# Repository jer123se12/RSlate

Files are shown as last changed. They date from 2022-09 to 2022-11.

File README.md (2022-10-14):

# RSlate
A 40key acrylic stack keyboard that is either hotswap with low profile switches or normal one but not hotswap.
Supports Vial
Currently Done!
---
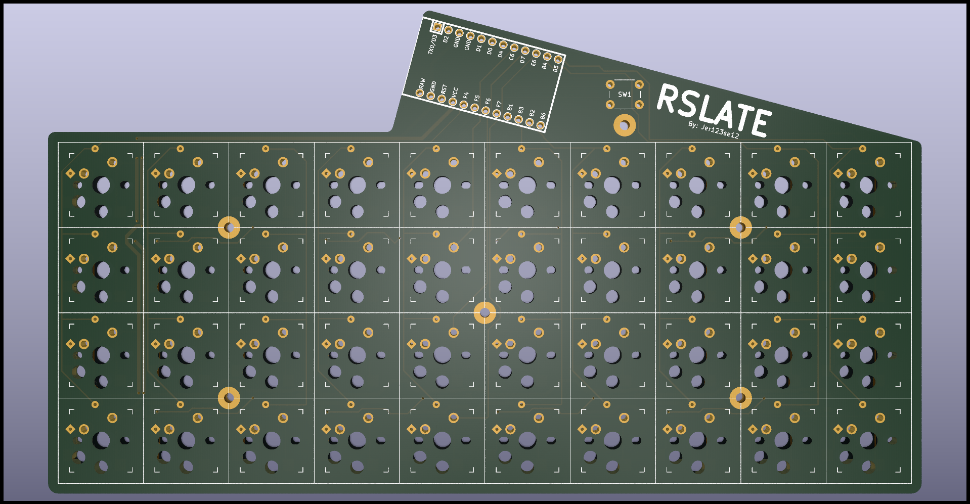
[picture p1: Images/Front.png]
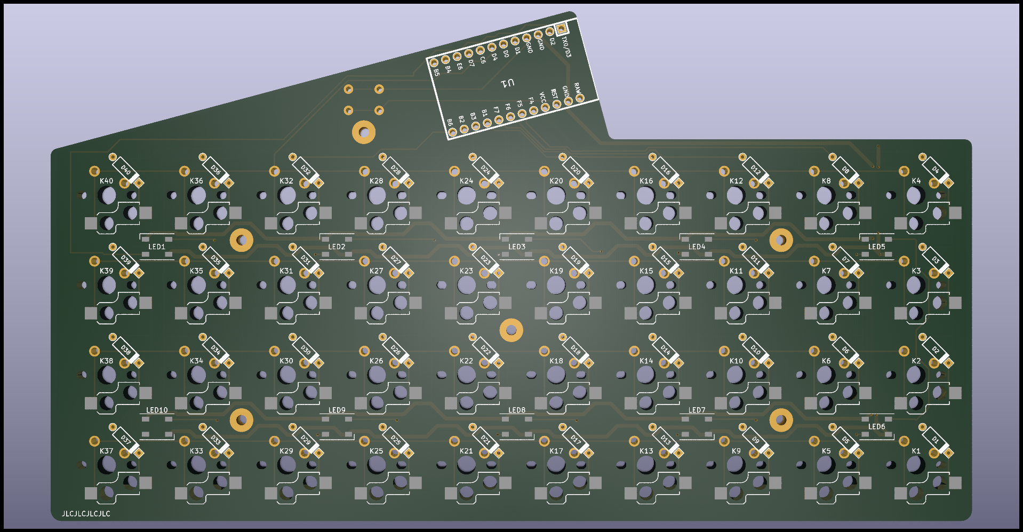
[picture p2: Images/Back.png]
|||
|---|---|
|Front|Back|
---
3d files are at [here](https://cad.onshape.com/documents/8e13d1f4745863165f092818/w/d03652fcd09787199e2b8651/e/c43cd68ad85962de6582dd97)

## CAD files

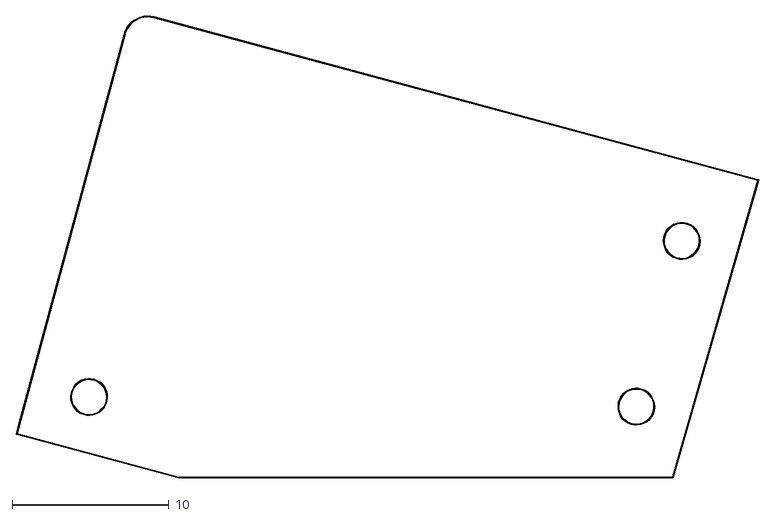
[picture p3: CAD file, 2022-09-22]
kicad/Final Files/plate/promicro.dxf
47.3 x 29.4

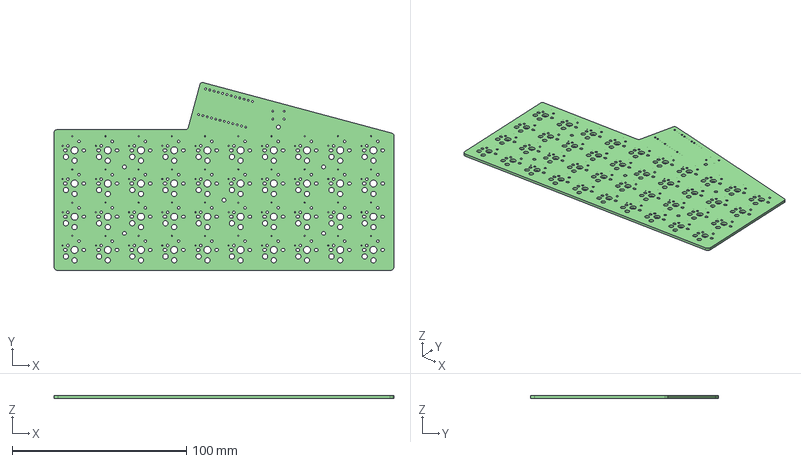
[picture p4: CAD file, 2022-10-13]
kicad/V4.step
195.1 x 107.9 x 1.60 mm

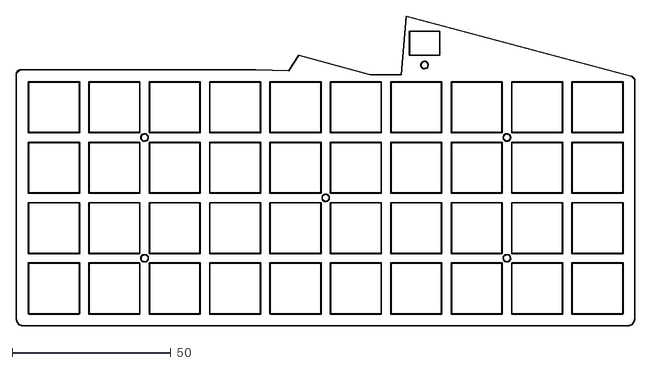
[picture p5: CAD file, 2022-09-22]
kicad/Final Files/plate/middle.dxf
195.1 x 97.8

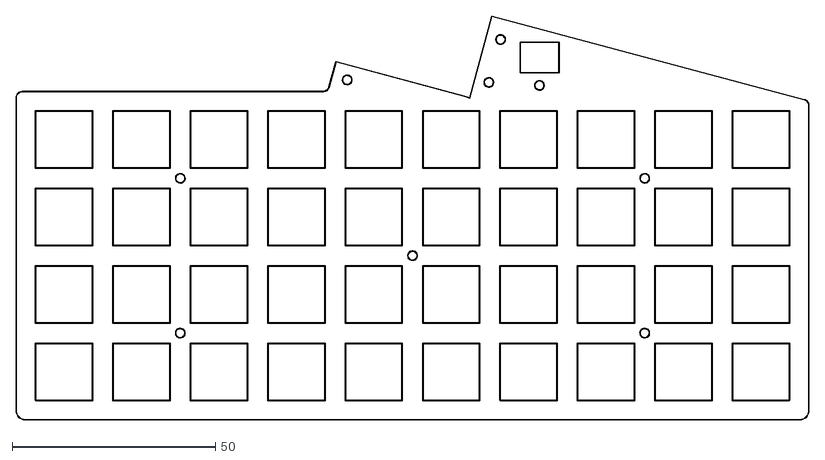
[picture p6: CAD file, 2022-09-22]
kicad/Final Files/plate/plate.dxf
195.1 x 99.4

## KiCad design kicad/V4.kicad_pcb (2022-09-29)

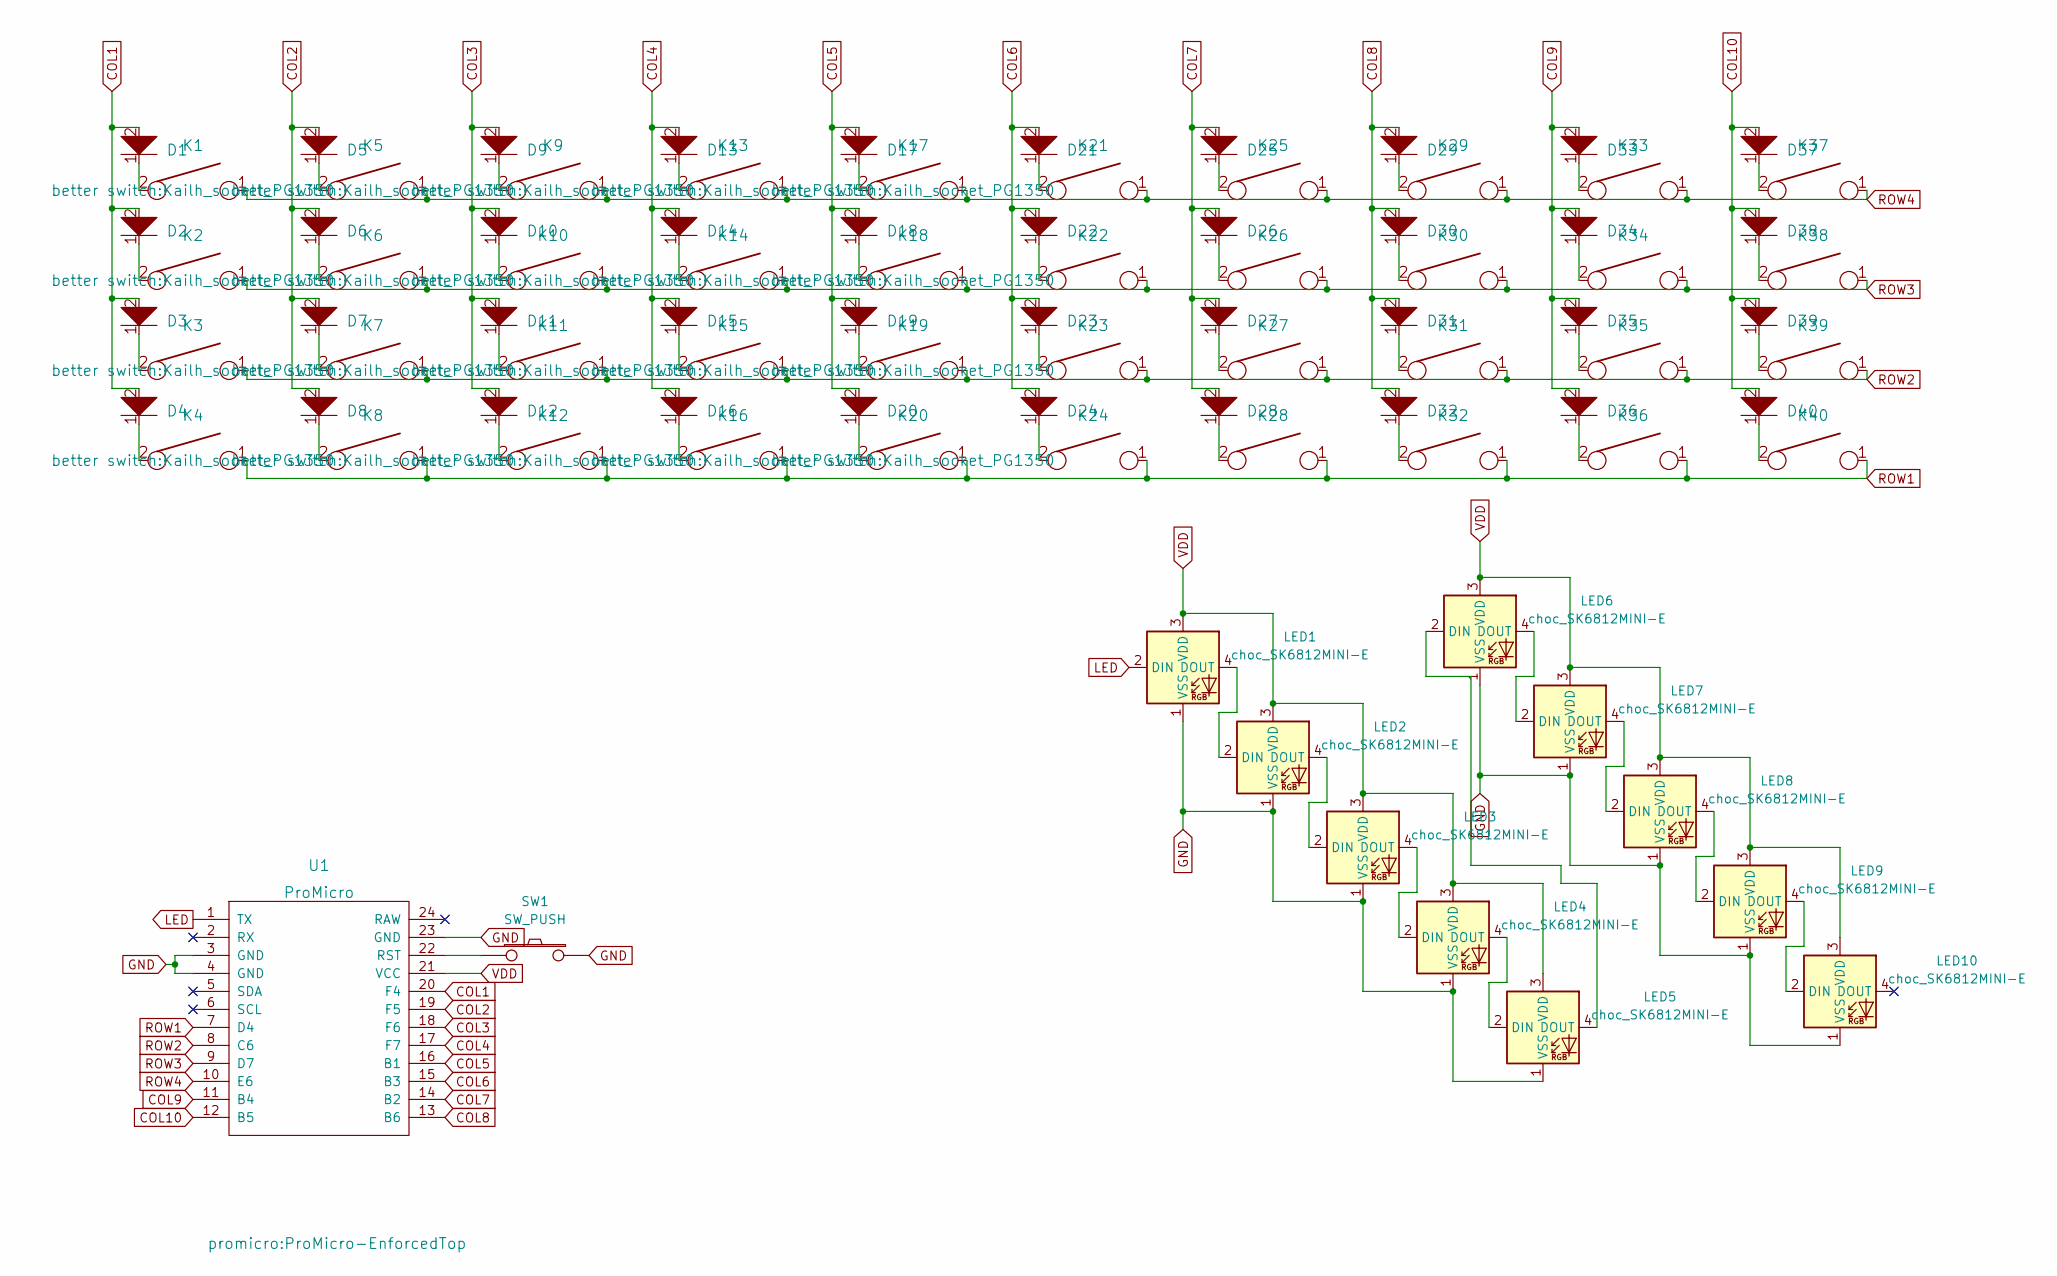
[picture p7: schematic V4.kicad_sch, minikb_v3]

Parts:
D1, D2, D3, D4, D5, D6, D7, D8, D9, D10, D11, D12, D13, D14, D15, D16, D17, D18, D19, D20, D21, D22, D23, D24, D25, D26, D27, D28, D29, D30, D31, D32, D33, D34, D35, D36, D37, D38, D39, D40: D; D_axial
K1, K2, K3, K4, K5, K6, K7, K8, K9, K10, K11, K12, K13, K14, K15, K16, K17, K18, K19, K20, K21, K22, K23, K24, K25, K26, K27, K28, K29, K30, K31, K32, K33, K34, K35, K36, K37, K38, K39, K40: KEYSW; Kailh_socket_PG1350
LED1, LED2, LED3, LED4, LED5, LED6, LED7, LED8, LED9, LED10: choc_SK6812MINI-E; LED_SK6812_PLCC4_5.0x5.0mm_P3.2mm
SW1: SW_PUSH; SW_PUSH_6mm
U1: ProMicro; ProMicro-EnforcedTop

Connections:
COL1: D1.2, D2.2, D3.2, D4.2, U1.20 (F4)
COL2: D5.2, D6.2, D7.2, D8.2, U1.19 (F5)
COL3: D9.2, D10.2, D11.2, D12.2, U1.18 (F6)
COL4: D13.2, D14.2, D15.2, D16.2, U1.17 (F7)
COL5: D17.2, D18.2, D19.2, D20.2, U1.16 (B1)
COL6: D21.2, D22.2, D23.2, D24.2, U1.15 (B3)
COL7: D25.2, D26.2, D27.2, D28.2, U1.14 (B2)
COL8: D29.2, D30.2, D31.2, D32.2, U1.13 (B6)
COL9: D33.2, D34.2, D35.2, D36.2, U1.11 (B4)
COL10: D37.2, D38.2, D39.2, D40.2, U1.12 (B5)
GND: LED1.1 (VSS), LED2.1 (VSS), LED3.1 (VSS), LED4.1 (VSS), LED5.1 (VSS), LED6.1 (VSS), LED7.1 (VSS), LED8.1 (VSS), LED9.1 (VSS), LED10.1 (VSS), SW1.2, U1.3 (GND), U1.4 (GND), U1.23 (GND)
LED: LED1.2 (DIN), U1.1 (TX)
unnamed: D1.1, K1.2
unnamed: D2.1, K2.2
unnamed: D3.1, K3.2
unnamed: D4.1, K4.2
unnamed: D5.1, K5.2
unnamed: D6.1, K6.2
unnamed: D7.1, K7.2
unnamed: D8.1, K8.2
unnamed: D9.1, K9.2
unnamed: D10.1, K10.2
unnamed: D11.1, K11.2
unnamed: D12.1, K12.2
unnamed: D13.1, K13.2
unnamed: D14.1, K14.2
unnamed: D15.1, K15.2
unnamed: D16.1, K16.2
unnamed: D17.1, K17.2
unnamed: D18.1, K18.2
unnamed: D19.1, K19.2
unnamed: D20.1, K20.2
unnamed: D21.1, K21.2
unnamed: D22.1, K22.2
unnamed: D23.1, K23.2
unnamed: D24.1, K24.2
unnamed: D25.1, K25.2
unnamed: D26.1, K26.2
unnamed: D27.1, K27.2
unnamed: D28.1, K28.2
unnamed: D29.1, K29.2
unnamed: D30.1, K30.2
unnamed: D31.1, K31.2
unnamed: D32.1, K32.2
unnamed: D33.1, K33.2
unnamed: D34.1, K34.2
unnamed: D35.1, K35.2
unnamed: D36.1, K36.2
unnamed: D37.1, K37.2
unnamed: D38.1, K38.2
unnamed: D39.1, K39.2
unnamed: D40.1, K40.2
unnamed: LED1.4 (DOUT), LED2.2 (DIN)
unnamed: LED2.4 (DOUT), LED3.2 (DIN)
unnamed: LED3.4 (DOUT), LED4.2 (DIN)
unnamed: LED4.4 (DOUT), LED5.2 (DIN)
unnamed: LED5.4 (DOUT), LED6.2 (DIN)
unnamed: LED6.4 (DOUT), LED7.2 (DIN)
unnamed: LED7.4 (DOUT), LED8.2 (DIN)
unnamed: LED8.4 (DOUT), LED9.2 (DIN)
unnamed: LED9.4 (DOUT), LED10.2 (DIN)
unnamed: SW1.1, U1.22 (RST)
ROW1: K4.1, K8.1, K12.1, K16.1, K20.1, K24.1, K28.1, K32.1, K36.1, K40.1, U1.7 (D4)
ROW2: K3.1, K7.1, K11.1, K15.1, K19.1, K23.1, K27.1, K31.1, K35.1, K39.1, U1.8 (C6)
ROW3: K2.1, K6.1, K10.1, K14.1, K18.1, K22.1, K26.1, K30.1, K34.1, K38.1, U1.9 (D7)
ROW4: K1.1, K5.1, K9.1, K13.1, K17.1, K21.1, K25.1, K29.1, K33.1, K37.1, U1.10 (E6)
VDD: LED1.3 (VDD), LED2.3 (VDD), LED3.3 (VDD), LED4.3 (VDD), LED5.3 (VDD), LED6.3 (VDD), LED7.3 (VDD), LED8.3 (VDD), LED9.3 (VDD), LED10.3 (VDD), U1.21 (VCC)

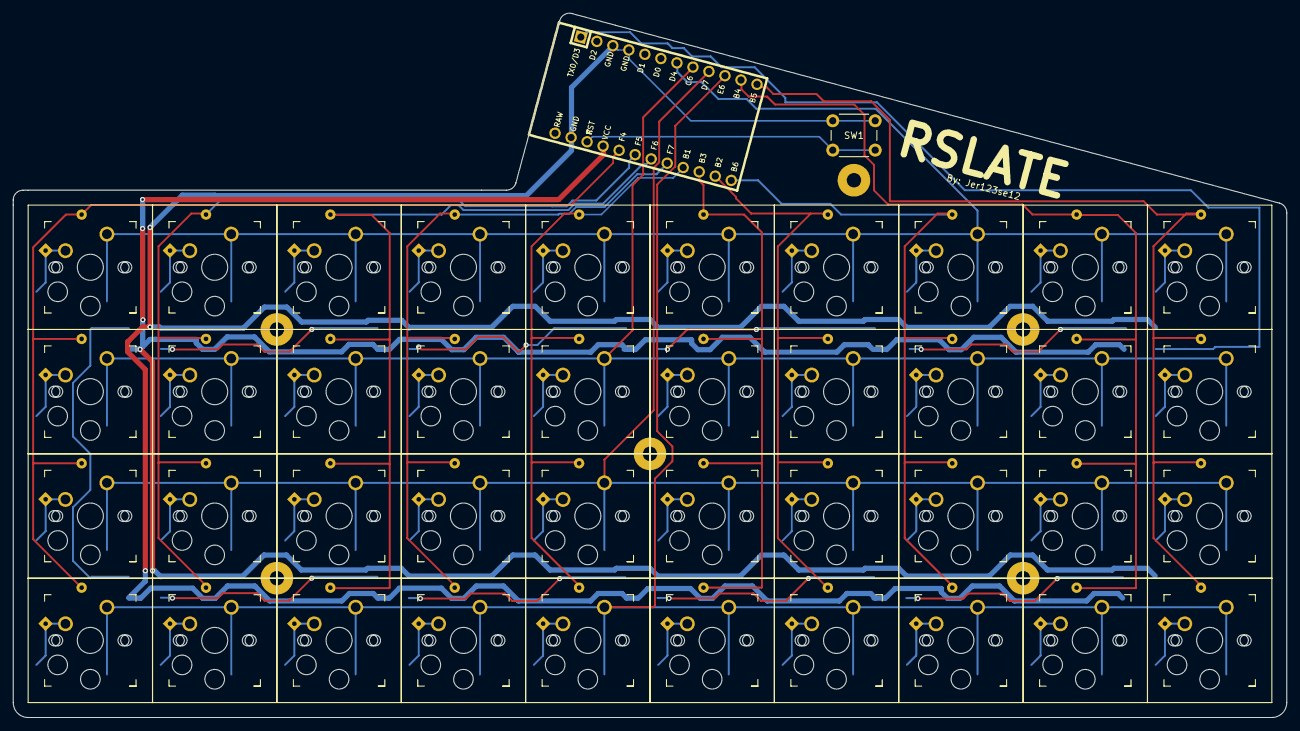
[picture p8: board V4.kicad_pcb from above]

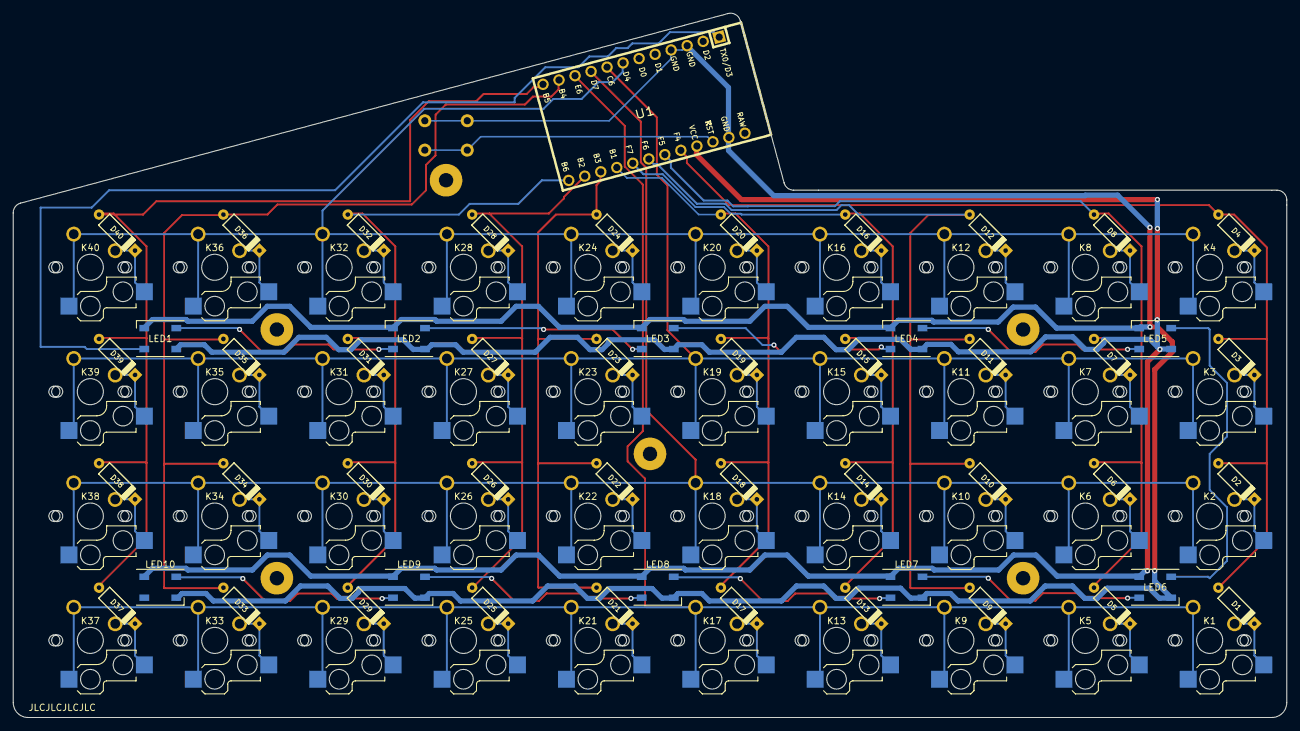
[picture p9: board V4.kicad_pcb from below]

Board: 2 copper layers, 195.1 x 107.9 mm, 98 parts (51 on the bottom side), 67 nets.

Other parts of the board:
H1, H1#2, H1#3, H1#4, H1#5, H1#6: M2; MountingHole_M2

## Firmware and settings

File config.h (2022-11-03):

/*
Copyright 2021 Zach White

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
You should have received a copy of the GNU General Public License
along with this program.  If not, see <http://www.gnu.org/licenses/>.
*/



#pragma once

#include "config_common.h"

/* USB Device descriptor parameter */
#define VENDOR_ID       0xFEED
#define PRODUCT_ID      0xBACA
#define DEVICE_VER      0x0001
#define MANUFACTURER    Jerick
#define PRODUCT         RSlate
#define DESCRIPTION     "40% keyboard with underglow!"

/* key matrix size */
#define MATRIX_ROWS 4
#define MATRIX_COLS 10

/* key matrix pins */
#define MATRIX_ROW_PINS {D4,C6,D7,E6} 
#define MATRIX_COL_PINS {F4,F5,F6,F7,B1,B3,B2,B6,B4,B5}  

/* COL2ROW or ROW2COL */
#define DIODE_DIRECTION COL2ROW
#define QMK_KEYS_PER_SCAN 40
#define USB_POLLING_INTERVAL_MS 0
#define FORCE_NKRO
#define RGB_DI_PIN D3
#define DRIVER_LED_TOTAL 10
#define RGB_MATRIX_FRAMEBUFFER_EFFECTS
#define RGB_MATRIX_KEYPRESSES
// RGB_Matrix settings
//#ifdef RGB_MATRIX_ENABLE
  #define ENABLE_RGB_MATRIX_KEYPRESSES // reacts to keypresses
  #define RGB_DISABLE_WHEN_USB_SUSPENDED true // turn off effects when suspended
  #define RGB_MATRIX_LED_FLUSH_LIMIT 16 // limits in milliseconds how frequently an animation will update the LEDs. 16 (16ms) is equivalent to limiting to 60fps (increases keyboard responsiveness)
  #define RGB_MATRIX_MAXIMUM_BRIGHTNESS 255 // limits maximum brightness of LEDs to 150 out of 255. Higher may cause the controller to crash.
  #define RGB_MATRIX_HUE_STEP 8
  #define RGB_MATRIX_SAT_STEP 8
  #define RGB_MATRIX_VAL_STEP 8
  #define RGB_MATRIX_SPD_STEP 10
  /* Disable the animations you don't want/need.  You will need to disable a good number of these
    because they take up a lot of space.  Disable until you can successfully compile your firmware. */
   #define ENABLE_RGB_MATRIX_ALPHAS_MODS
  // #define DISABLE_RGB_MATRIX_GRADIENT_UP_DOWN
  #define ENABLE_RGB_MATRIX_BREATHING
  #define ENABLE_RGB_MATRIX_CYCLE_ALL
  #define ENABLE_RGB_MATRIX_CYCLE_LEFT_RIGHT
  #define ENABLE_RGB_MATRIX_CYCLE_UP_DOWN
  #define ENABLE_RGB_MATRIX_CYCLE_OUT_IN
  #define ENABLE_RGB_MATRIX_CYCLE_OUT_IN_DUAL
  #define ENABLE_RGB_MATRIX_RAINBOW_MOVING_CHEVRON
  #define ENABLE_RGB_MATRIX_DUAL_BEACON
  //#define DISABLE_RGB_MATRIX_RAINBOW_BEACON
  //#define DISABLE_RGB_MATRIX_RAINBOW_PINWHEELS
  // #define DISABLE_RGB_MATRIX_RAINDROPS
  #define ENABLE_RGB_MATRIX_JELLYBEN_RAINDROPS
  # define ENABLE_RGB_MATRIX_TYPING_HEATMAP
  #define ENABLE_RGB_MATRIX_DIGITAL_RAIN
  #define ENABLE_RGB_MATRIX_SOLID_REACTIVE
  //#define ENABLE_RGB_MATRIX_SOLID_REACTIVE_SIMPLE
  #define ENABLE_RGB_MATRIX_SOLID_REACTIVE_WIDE
  //#define ENABLE_RGB_MATRIX_SOLID_REACTIVE_CROSS
  #define ENABLE_RGB_MATRIX_SOLID_REACTIVE_MULTICROSS
  //#define ENABLE_RGB_MATRIX_SOLID_REACTIVE_NEXUS
  #define ENABLE_RGB_MATRIX_SOLID_REACTIVE_MULTINEXUS
  //#define ENABLE_RGB_MATRIX_SPLASH
  #define ENABLE_RGB_MATRIX_MULTISPLASH
  //#define ENABLE_RGB_MATRIX_SOLID_SPLASH
  #define ENABLE_RGB_MATRIX_SOLID_MULTISPLASH
//#endif //RGB_MATRIX_ENABLE

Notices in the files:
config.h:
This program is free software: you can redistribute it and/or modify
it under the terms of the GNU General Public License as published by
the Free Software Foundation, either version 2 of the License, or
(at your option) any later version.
